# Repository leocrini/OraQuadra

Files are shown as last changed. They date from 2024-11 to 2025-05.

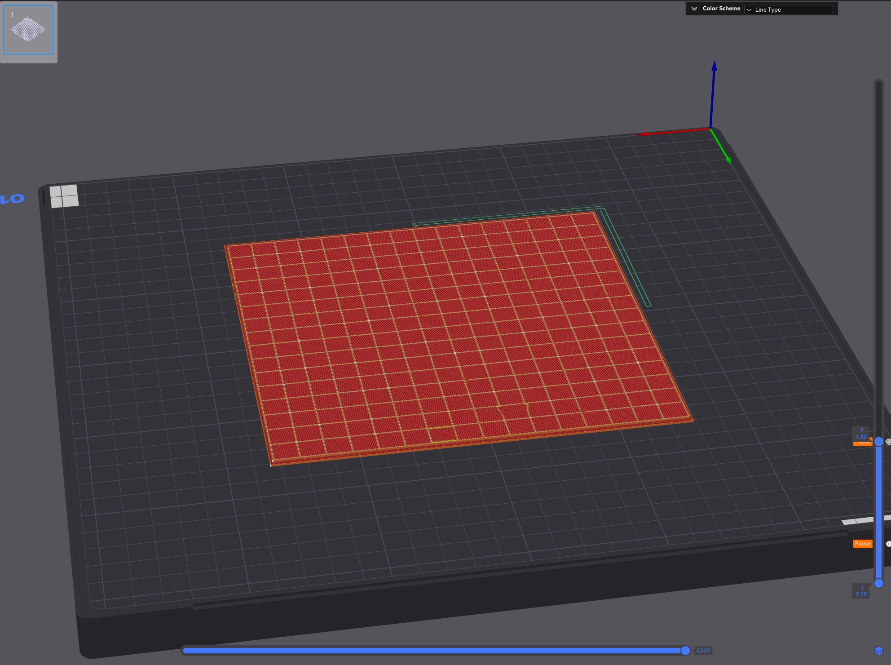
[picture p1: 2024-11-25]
3D/Frontale Monocolore/Pausa al layer 9.jpg

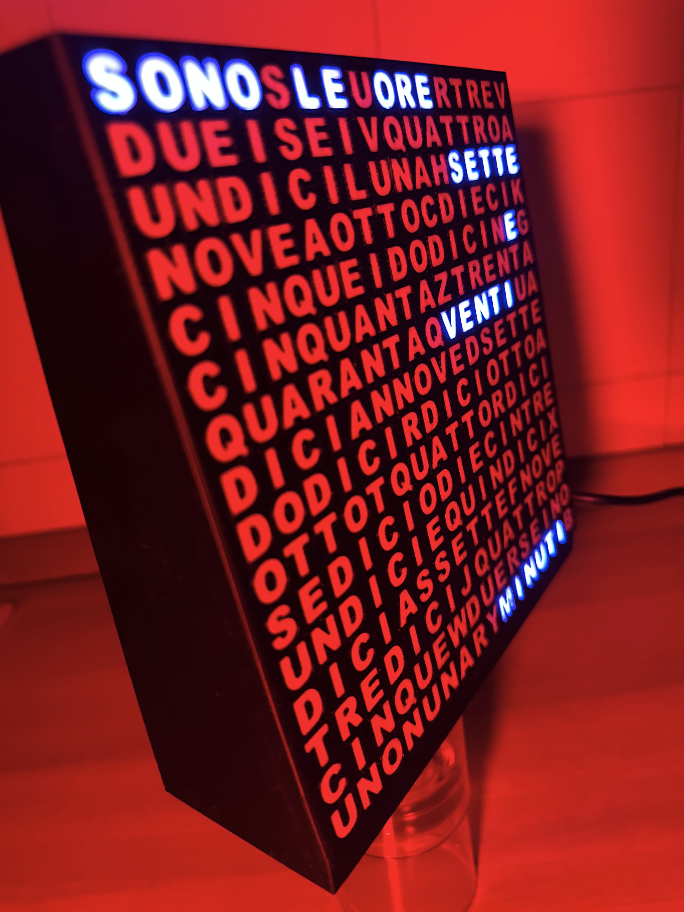
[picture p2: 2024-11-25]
IMMAGINI/IMG_9131.jpg

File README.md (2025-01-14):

# OraQuadra
Le parole in tempo

Un progetto per la comunità, per un simpatico orologio derivato dal progetto Word Clock, ma totalmente personalizzato e con tutto il necessario per poterselo replicare facilmente.
Video tutorial qui: https://youtu.be/s_7UZaXF4Ug





EPXX-OraQuadra



Nuova Versione che mostra l'ora nel formato 24 ore.

Versione_24_ore

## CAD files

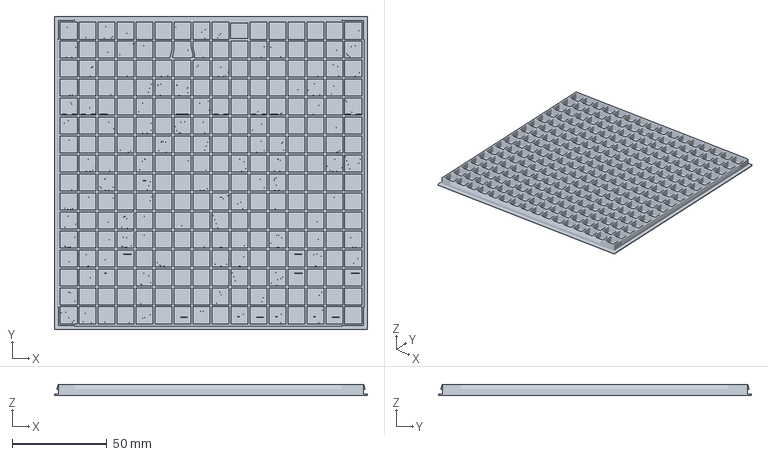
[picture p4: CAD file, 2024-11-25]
3D/BAMBULAB/Frontale_Bambulab.3mf
165.0 x 165.0 x 6.00 mm

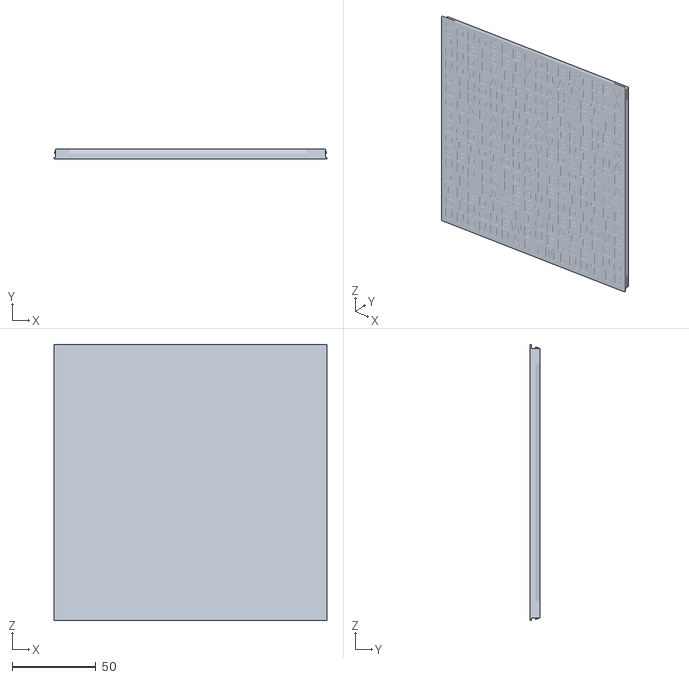
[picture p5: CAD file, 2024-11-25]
3D/Frontale Monocolore/Frontale Monocolore.stl
163.0 x 6.00 x 165.0

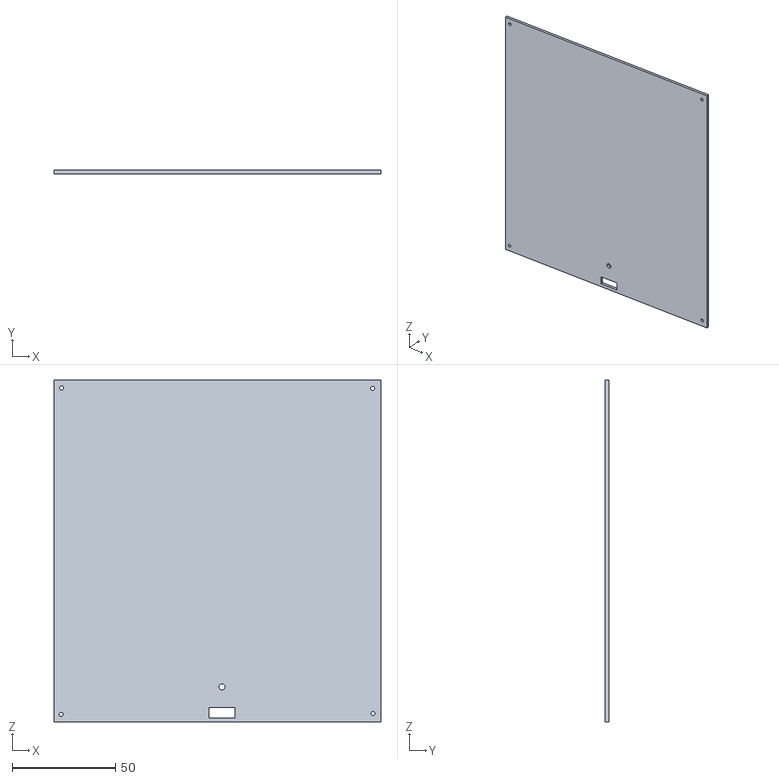
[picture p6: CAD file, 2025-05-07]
3D/Schiena da tavolo.stl
158.5 x 1.70 x 166.0

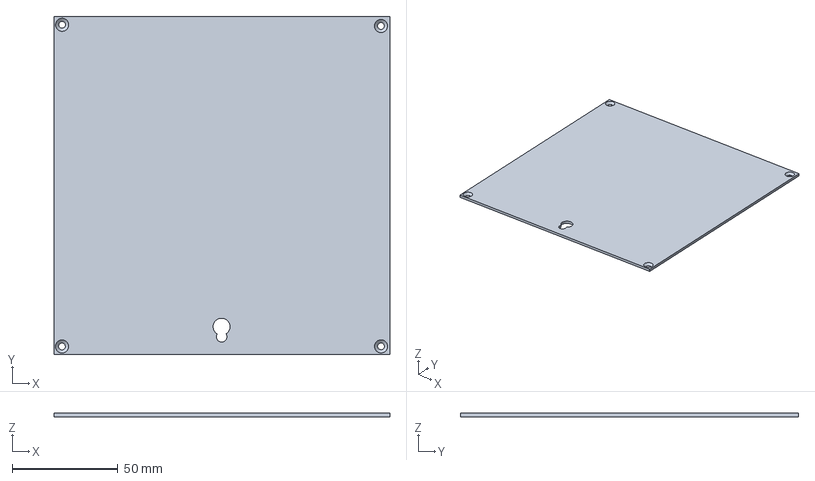
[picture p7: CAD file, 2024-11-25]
3D/BAMBULAB/Schiena da muro_bambulab.3mf
158.5 x 159.6 x 1.70 mm

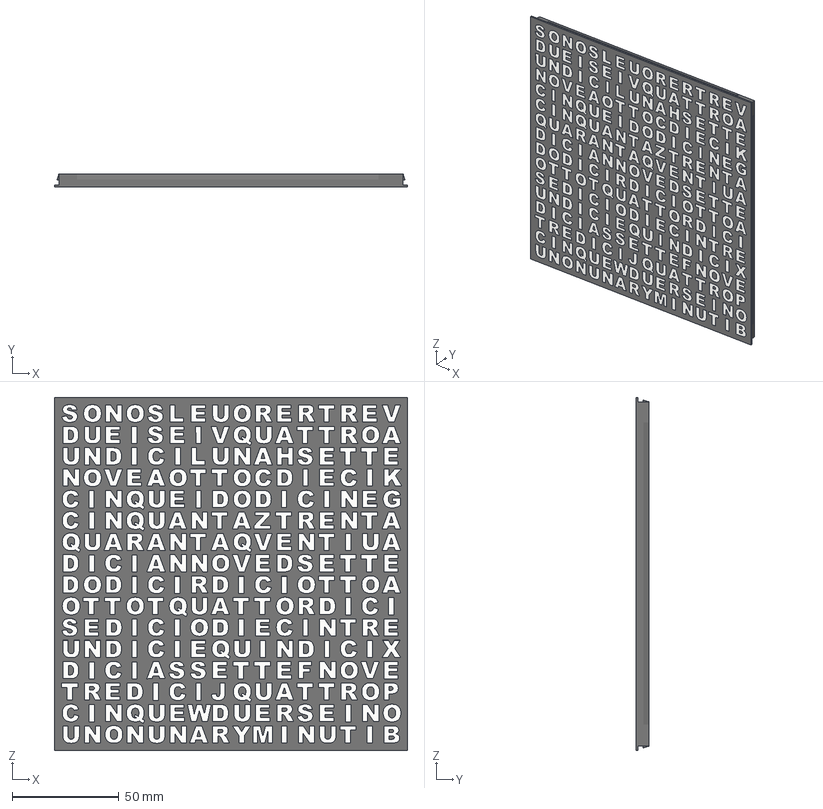
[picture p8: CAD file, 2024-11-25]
3D/Frontale Bicolore.3mf
165.0 x 6.00 x 165.0 mm
neoboard_led_diffuser_1mm_and_separator_4mm (1)
neoboard_led_diffuser_1mm_and_separator_4mm (10)
neoboard_led_diffuser_1mm_and_separator_4mm (11)
neoboard_led_diffuser_1mm_and_separator_4mm (12)
neoboard_led_diffuser_1mm_and_separator_4mm (13)
neoboard_led_diffuser_1mm_and_separator_4mm (14)
neoboard_led_diffuser_1mm_and_separator_4mm (15)
neoboard_led_diffuser_1mm_and_separator_4mm (16)
neoboard_led_diffuser_1mm_and_separator_4mm (17)
neoboard_led_diffuser_1mm_and_separator_4mm (18)
neoboard_led_diffuser_1mm_and_separator_4mm (19)
neoboard_led_diffuser_1mm_and_separator_4mm (2)
neoboard_led_diffuser_1mm_and_separator_4mm (20)
neoboard_led_diffuser_1mm_and_separator_4mm (21)
neoboard_led_diffuser_1mm_and_separator_4mm (22)
neoboard_led_diffuser_1mm_and_separator_4mm (23)
neoboard_led_diffuser_1mm_and_separator_4mm (24)
neoboard_led_diffuser_1mm_and_separator_4mm (25)
neoboard_led_diffuser_1mm_and_separator_4mm (26)
neoboard_led_diffuser_1mm_and_separator_4mm (27)
neoboard_led_diffuser_1mm_and_separator_4mm (28)
neoboard_led_diffuser_1mm_and_separator_4mm (29)
neoboard_led_diffuser_1mm_and_separator_4mm (3)
neoboard_led_diffuser_1mm_and_separator_4mm (30)
neoboard_led_diffuser_1mm_and_separator_4mm (31)
neoboard_led_diffuser_1mm_and_separator_4mm (32)
neoboard_led_diffuser_1mm_and_separator_4mm (33)
neoboard_led_diffuser_1mm_and_separator_4mm (34)
neoboard_led_diffuser_1mm_and_separator_4mm (35)
neoboard_led_diffuser_1mm_and_separator_4mm (36)
neoboard_led_diffuser_1mm_and_separator_4mm (37)
neoboard_led_diffuser_1mm_and_separator_4mm (38)
neoboard_led_diffuser_1mm_and_separator_4mm (39)
neoboard_led_diffuser_1mm_and_separator_4mm (4)
neoboard_led_diffuser_1mm_and_separator_4mm (40)
neoboard_led_diffuser_1mm_and_separator_4mm (41)
neoboard_led_diffuser_1mm_and_separator_4mm (42)
neoboard_led_diffuser_1mm_and_separator_4mm (43)
neoboard_led_diffuser_1mm_and_separator_4mm (44)
neoboard_led_diffuser_1mm_and_separator_4mm (45)
neoboard_led_diffuser_1mm_and_separator_4mm (46)
neoboard_led_diffuser_1mm_and_separator_4mm (47)
neoboard_led_diffuser_1mm_and_separator_4mm (48)
neoboard_led_diffuser_1mm_and_separator_4mm (49)
neoboard_led_diffuser_1mm_and_separator_4mm (5)
neoboard_led_diffuser_1mm_and_separator_4mm (50)
neoboard_led_diffuser_1mm_and_separator_4mm (51)
neoboard_led_diffuser_1mm_and_separator_4mm (52)
neoboard_led_diffuser_1mm_and_separator_4mm (53)
neoboard_led_diffuser_1mm_and_separator_4mm (54)
neoboard_led_diffuser_1mm_and_separator_4mm (55)
neoboard_led_diffuser_1mm_and_separator_4mm (56)
neoboard_led_diffuser_1mm_and_separator_4mm (57)
neoboard_led_diffuser_1mm_and_separator_4mm (58)
neoboard_led_diffuser_1mm_and_separator_4mm (59)
neoboard_led_diffuser_1mm_and_separator_4mm (6)
neoboard_led_diffuser_1mm_and_separator_4mm (60)
neoboard_led_diffuser_1mm_and_separator_4mm (61)
neoboard_led_diffuser_1mm_and_separator_4mm (62)
neoboard_led_diffuser_1mm_and_separator_4mm (63)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

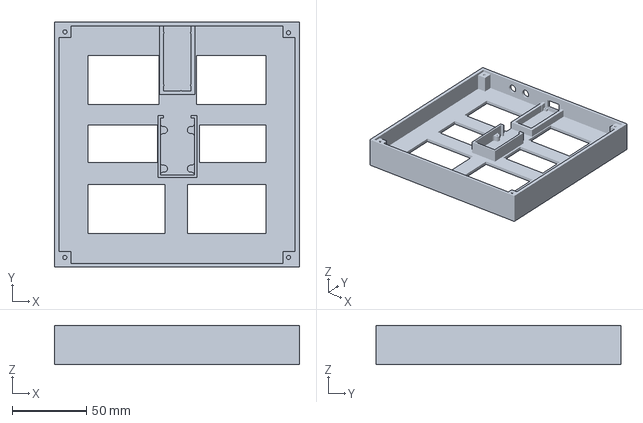
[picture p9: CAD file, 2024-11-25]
3D/BAMBULAB/Corpo da muro_bambulab.3mf
165.0 x 164.9 x 26.5 mm

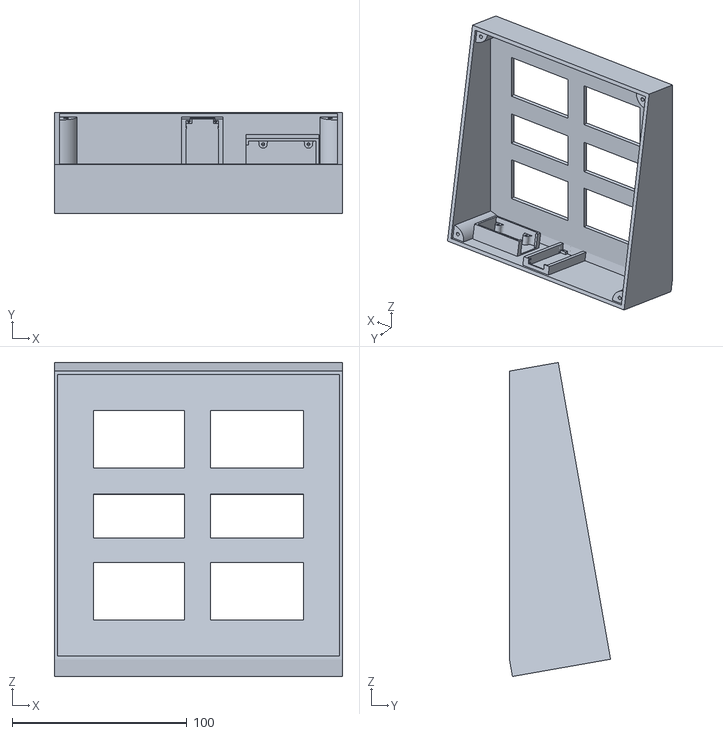
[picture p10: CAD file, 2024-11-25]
3D/Corpo da tavolo.stl
165.0 x 57.9 x 179.8

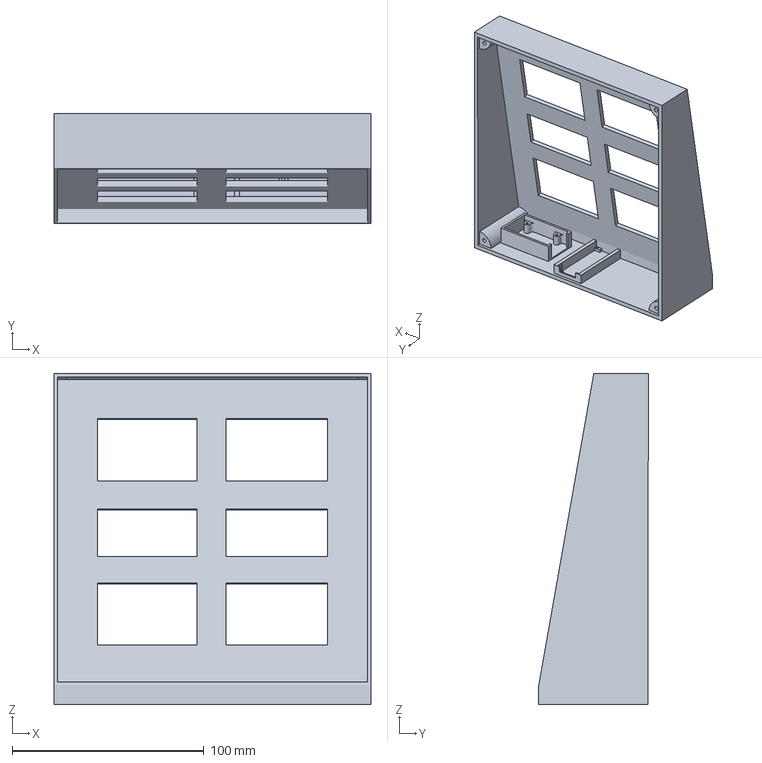
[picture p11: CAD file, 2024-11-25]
3D/BAMBULAB/Corpo da tavolo_bambulab.3mf
165.0 x 57.1 x 172.5 mm

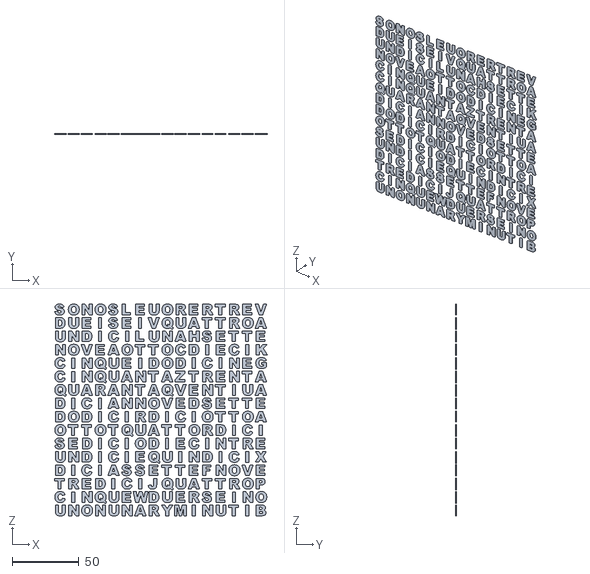
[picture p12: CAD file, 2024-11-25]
3D/Frontale bicolore lettere.stl
159.1 x 1.00 x 158.3

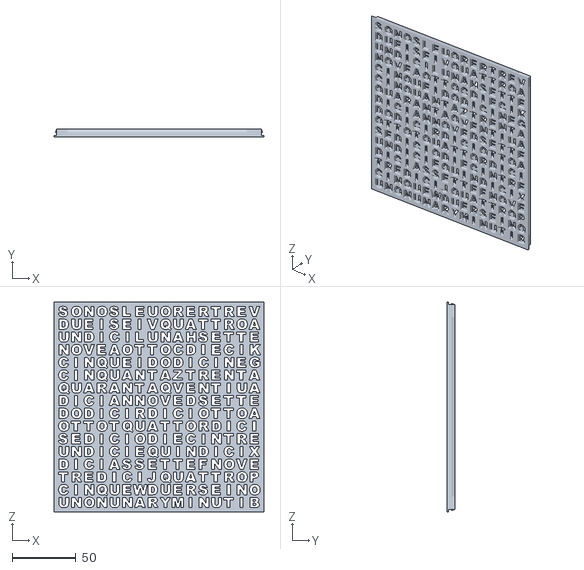
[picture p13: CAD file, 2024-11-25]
3D/Frontale bicolore corpo.stl
165.0 x 6.00 x 165.0

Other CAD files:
3D/BAMBULAB/Schiena da tavolo_bambulab.3mf
3D/Schiena da muro.stl
3D/Corpo da muro.stl

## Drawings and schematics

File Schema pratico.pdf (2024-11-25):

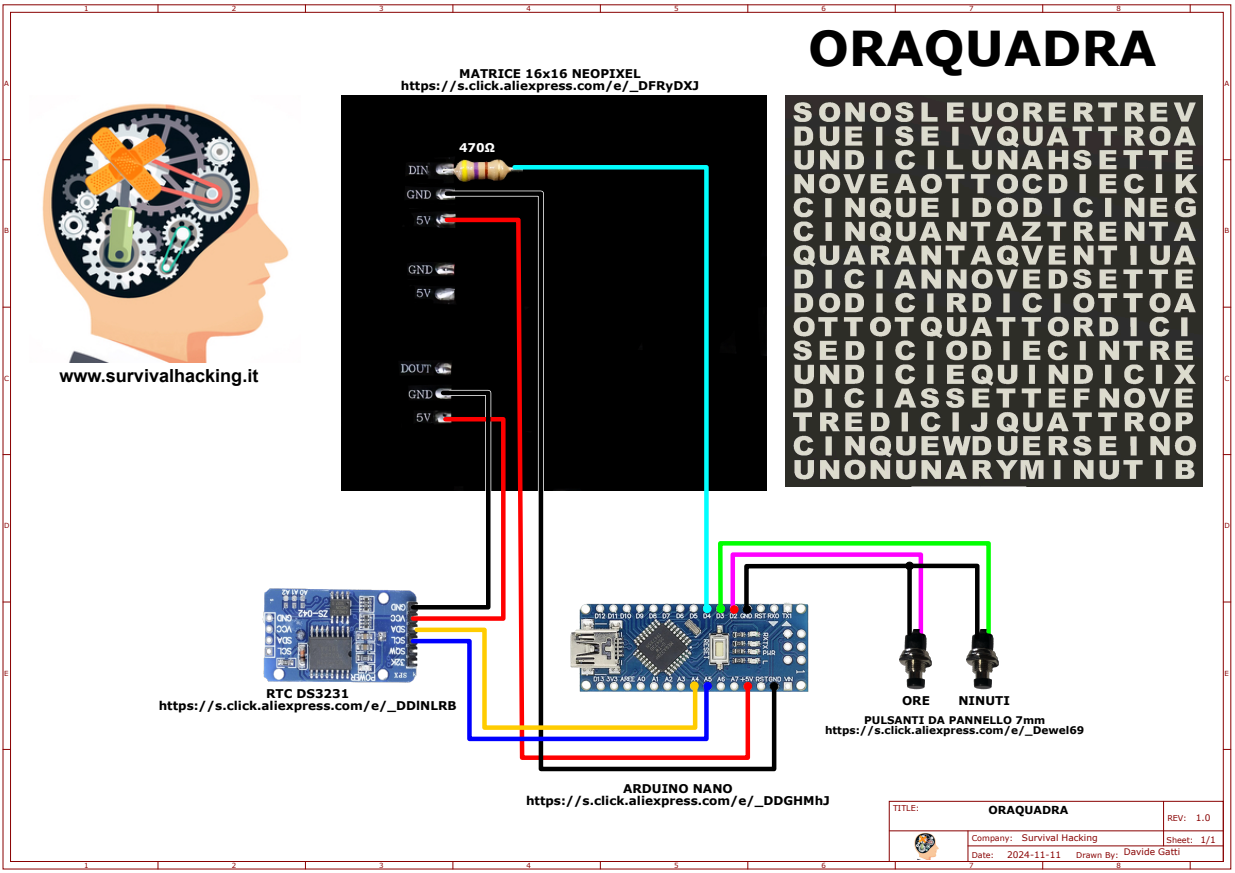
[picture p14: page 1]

https://s.click.aliexpress.com/e/_DFRyDXJ

https://s.click.aliexpress.com/e/_DDlNLRB

https://s.click.aliexpress.com/e/_Dewel69

https://s.click.aliexpress.com/e/_DDGHMhJ

TITLE: ORAQUADRA | REV: 1.0

Company: Survival Hacking | Sheet: 1/1

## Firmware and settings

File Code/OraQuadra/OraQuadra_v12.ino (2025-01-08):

// OraQuadra V1.2
// By Davide Gatti SURVIVAL HACKING  www.survivalhacking.it
//
// Setup:
//
// Pulsante 1 = per la regolazione dell'ora
// Pulsante 2 = per la regolazione deli minuti
// Pulsante 1 + Pulsante 2 = cambio preset 0=Sfumato bianco  1-5=Scrittura lenta vari colori  6-10=Scrittira veloce vari colori 11=Matrix classico 12=Multicolor fill
//
// Cambiati valori di luminosità di default per evitare che si bruci Arduino per l'eccessivo assorbimento della matrice LED 
//
// Modificato da Angelo Carrieri il 08/01/2025 con l'aggiunta di altri due modalità
// Modo 11=Effetto matrix classico
// Modo 12=Effetto multicolor fill

#include "RTClib.h"
#include <Adafruit_NeoPixel.h>
#include <EEPROM.h>

RTC_DS3231 rtc;       // Istanza per usare l'RTC

//Definizioni per neopixel
#define PIN   4        // pin neopixel
#define NUMPIXELS 256  // 16 x 16
#define GIORNO 64     // Luminosità di giorno (Attenzione, non alzare troppo questo valore visto che la matrice è alimentata dall'arduino che potrebbe bruciarsi se esagerate)
#define NOTTE 32       // Luminosità di notte

Adafruit_NeoPixel strip(NUMPIXELS, PIN, NEO_GRB + NEO_KHZ800);
byte intBrightness;

//Definizione colori
uint32_t Red = strip.Color(255, 0, 0); 
uint32_t Green = strip.Color( 0, 255, 0);
uint32_t Blue = strip.Color( 0, 0, 255);
uint32_t White = strip.Color( 255, 255, 255);
uint32_t Yellow = strip.Color( 255, 255, 0);
uint32_t Purple = strip.Color( 60, 0, 255);
uint32_t Gray = strip.Color( 128, 128, 128);
uint32_t Off = strip.Color( 0, 0, 0);

byte P1= 3; // Tasto O  avanzamento ore
byte P2= 2; // Tasto M  avanzamento minuti

byte oracorrente;        // variabile ora corrente
byte oraprecedente;      // variabile ora precedente
byte minutocorrente;     // variabile minuto corrente
byte minutoprecedente;   // variabile minuto precedente
byte mode;               // variabile per la modalità   
byte modo;               // variabile per la modalità mirror
byte Presets;            // Preset corrente
uint32_t Colore;         // Variabile per il passaggio colore
byte ledstrip[NUMPIXELS];   // Array di 256 byte per mappare i led da accendere per effetto Matrix

// Mappatura matrice
// S-015 O-014 N-013 O-012 S-011 L-010 E-009 U-008 O-007 R-006 E-005 R-004 T-003 R-002 E-001 V-000
// D-016 U-017 E-018 I-019 S-020 E-021 I-022 V-023 Q-024 U-025 A-026 T-027 T-028 R-029 O-030 A-031
// U-047 N-046 D-045 I-044 C-043 I-042 L-041 U-040 N-039 A-038 H-037 S-036 E-035 T-034 T-033 E-032
// N-048 O-049 V-050 E-051 A-052 O-053 T-054 T-055 O-056 C-057 D-058 I-059 E-060 C-061 I-062 K-063
// C-079 I-078 N-077 Q-076 U-075 E-074 I-073 D-072 O-071 D-070 I-069 C-068 I-067 N-066 E-065 G-064
// C-080 I-081 N-082 Q-083 U-084 A-085 N-086 T-087 A-088 Z-089 T-090 R-091 E-092 N-093 T-094 A-095
// Q-111 U-110 A-109 R-108 A-107 N-106 T-105 A-104 Q-103 V-102 E-101 N-100 T-099 I-098 U-097 A-096
// D-112 I-113 C-114 I-115 A-116 N-117 N-118 O-119 V-120 E-121 D-122 S-123 E-124 T-125 T-126 E-127
// D-143 O-142 D-141 I-140 C-139 I-138 R-137 D-136 I-135 C-134 I-133 O-132 T-131 T-130 O-129 A-128
// O-144 T-145 T-146 O-147 T-148 Q-149 U-150 A-151 T-152 T-153 O-154 R-155 D-156 I-157 C-158 I-159
// S-175 E-174 D-173 I-172 C-171 I-170 O-169 D-168 I-167 E-166 C-165 I-164 N-163 T-162 R-161 E-160
// U-176 N-177 D-178 I-179 C-180 I-181 E-182 Q-183 U-184 I-185 N-186 D-187 I-188 C-189 I-190 X-191
// D-207 I-206 C-205 I-204 A-203 S-202 S-201 E-200 T-199 T-198 E-197 F-196 N-195 O-194 V-193 E-192
// T-208 R-209 E-210 D-211 I-212 C-213 I-214 J-215 Q-216 U-217 A-218 T-219 T-220 R-221 O-222 P-223
// C-239 I-238 N-237 Q-236 U-235 E-234 W-233 D-232 U-231 E-230 R-229 S-228 E-227 I-226 N-225 O-224
// U-240 N-241 O-242 N-243 U-244 N-245 A-246 R-247 Y-248 M-249 I-250 N-251 U-252 T-253 I-254 B-255


//Definizione testi vari
byte  txtSONOLEORE[] = {15,14,13,12,10,9,7,6,5,255};
byte  txtSURVIVAL[] = {11,8,4,0,19,23,31,41,37,52,57,63,73,66,64,255};
byte  txtMINUTI[] = {249,250,251,252,253,254,255};

//Definizione delle stringhe delle ore
byte  txtUNA[] = {38,39,40,255};
byte  txtDUE[] = {16,17,18,255};
byte  txtTRE[] = {1,2,3,255};
byte  txtQUATTRO[] = {24,25,26,27,28,29,30,255};
byte  txtCINQUE[] = {79,78,77,76,75,74,255};
byte  txtSEI[] = {20,21,22,255};
byte  txtSETTE[] = {32,33,34,35,36,255};
byte  txtOTTO[] = {53,54,55,56,255};
byte  txtNOVE[] = {48,49,50,51,255};
byte  txtDIECI[] = {58,59,60,61,62,255};
byte  txtUNDICI[] = {42,43,44,45,46,47,255};
byte  txtDODOCI[] = {67,68,69,70,71,72,255};

// Definizione delle stringhe dei minuti
byte  txtE[] = {65,255};
byte  txtMUNO[] = {240,241,242,255};
byte  txtMDUE[] = {230,231,232,255};
byte  txtMTRE[] = {160,161,162,255};
byte  txtMQUATTRO[] = {216,217,218,219,220,221,222,255};
byte  txtMCINQUE[] = {234,235,236,237,238,239,255};
byte  txtMSEI[] = {226,227,228,255};
byte  txtMSETTE[] = {123,124,125,126,127,255};
byte  txtMOTTO[] = {144,145,146,147,255};
byte  txtMNOVE[] = {192,193,194,195,255};
byte  txtMDIECI[] = {164,165,166,167,168,255};
byte  txtMUNDICI[] = {176,177,178,179,180,181,255};
byte  txtMDODICI[] = {138,139,140,141,142,143,255};
byte  txtMTREDICI[] = {208,209,210,211,212,213,214,255};
byte  txtMQUATTORDICI[] = {149,150,151,152,153,154,155,156,157,158,159,255};
byte  txtMQUINDICI[] = {183,184,185,186,187,188,189,190,255};
byte  txtMSEDICI[] = {170,171,172,173,174,175,255};
byte  txtMDICIASSETTE[] = {197,198,199,200,201,202,203,204,205,206,207,255};
byte  txtMDICIOTTO[] = {129,130,131,132,133,134,135,136,255};
byte  txtMDICIANNOVE[] = {112,113,114,115,116,117,118,119,120,121,255};
byte  txtMVENT[] = {99,100,101,102,255};
byte  txtMVENTI[] = {98,99,100,101,102,255};
byte  txtMTRENT[] = {90,91,92,93,94,255};
byte  txtMTRENTA[] = {90,91,92,93,94,95,255};
byte  txtMQUARANT[] = {105,106,107,108,109,110,111,255};
byte  txtMQUARANTA[] = {104,105,106,107,108,109,110,111,255};
byte  txtMCINQUANT[] = {80,81,82,83,84,85,86,87,255};
byte  txtMCINQUANTA[] = {80,81,82,83,84,85,86,87,88,255};


void setup () {
  if (EEPROM.read(0) != 0x55) {           // read configuration byte. If it is not 55h is not configured, than store a default values
    EEPROM.write(0, 0x55);                // write configuret marker
    EEPROM.write(1, 0);                   // scrivi il Preset di default
  }
  
  Presets=(EEPROM.read(1));               // Leggi eeprom e imposta il preset memorizzato
  Preset(Presets);                        // imposta il modo grafico del relativo preset

  strip.begin();                          // inizializza matrice neo pixel
  strip.clear();                          // spegni tutti i led della matrice  
  rainbow(1);                             // faiun effetto arcobaleno
  for (int i =0 ; i < 500; i++) {        // Scrivi SURVIVAL HACKING in multicolor e poi flash bianchi 
    paintWordFast(random(254),strip.Color( random(254), random(254), random(254)));
    strip.show();
  }
  
  for (int i =0 ; i < 5; i++) {           // Scrivi SURVIVAL HACKING in multicolor e poi flash bianchi 
    paintWordFast(txtSURVIVAL, Red);
    paintWordFast(txtSURVIVAL, Blue);
    paintWordFast(txtSURVIVAL, Yellow);
    paintWordFast(txtSURVIVAL, Green);
    paintWordFast(txtSURVIVAL, White);
  }
//  delay(1000);
  for (int i =0 ; i < 100; i++) {        // Scrivi SURVIVAL HACKING in multicolor e poi flash bianchi 
    paintWordFast(random(255),strip.Color(0,0,0));
    paintWordFast(random(255),strip.Color(0,0,0));
    paintWordFast(random(255),strip.Color(0,0,0));
    paintWordFast(random(255),strip.Color(0,0,0));
    paintWordFast(random(255),strip.Color(0,0,0));
    paintWordFast(random(255),strip.Color(0,0,0));
    paintWordFast(random(255),strip.Color(0,0,0));
    paintWordFast(random(255),strip.Color(0,0,0));
    paintWordFast(random(255),strip.Color(0,0,0));
    paintWordFast(random(255),strip.Color(0,0,0));
//    paintWordFast(txtSURVIVAL, Off);
//    delay(1);
//    paintWordFast(txtSURVIVAL, White);
    strip.show();
  }
  strip.clear();
  strip.show();
  strip.setPixelColor(11,White);
  strip.show();                           // aggiorna matrice neopixel
  delay(200);
  strip.setPixelColor(8,White);
  strip.show();                           // aggiorna matrice neopixel
  delay(200);
  strip.setPixelColor(4,White);
  strip.show();                           // aggiorna matrice neopixel
  delay(200);
  strip.setPixelColor(0,White);
  strip.show();                           // aggiorna matrice neopixel
  delay(200);
  strip.setPixelColor(19,White);
  strip.show();                           // aggiorna matrice neopixel
  delay(200);
  strip.setPixelColor(23,White);
  strip.show();                           // aggiorna matrice neopixel
  delay(200);
  strip.setPixelColor(31,White);
  strip.show();                           // aggiorna matrice neopixel
  delay(200);
  strip.setPixelColor(41,White);
  strip.show();                           // aggiorna matrice neopixel
  delay(200);
  strip.setPixelColor(37,White);
  strip.show();                           // aggiorna matrice neopixel
  delay(200);
  strip.setPixelColor(52,White);
  strip.show();                           // aggiorna matrice neopixel
  delay(200);
  strip.setPixelColor(57,White);
  strip.show();                           // aggiorna matrice neopixel
  delay(200);
  strip.setPixelColor(63,White);
  strip.show();                           // aggiorna matrice neopixel
  delay(200);
  strip.setPixelColor(73,White);
  strip.show();                           // aggiorna matrice neopixel
  delay(200);
  strip.setPixelColor(66,White);
  strip.show();                           // aggiorna matrice neopixel
  delay(200);
  strip.setPixelColor(64,White);
  strip.show();                           // aggiorna matrice neopixel
  delay(1000);
  paintWordFast(txtSURVIVAL, Red);
  strip.show();                           // aggiorna matrice neopixel
  delay(1000);

  strip.clear();                          // spegni tutti i led della matrice  
  strip.show();                           // aggiorna matrice neopixel

  pinMode(P1,INPUT_PULLUP);               // definisce il tipo di ingresso digitale con pullup
  pinMode(P2,INPUT_PULLUP);               // definisce il tipo di ingresso digitale con pullup

  oraprecedente =99;                      // impostazione variabile per aggiornamento forzato ora
  minutoprecedente =99;                   // impostazione variabile per aggiornamento forzato ora

  if (! rtc.begin()) {                    // inizializza RTC  
    while (1) delay(10);                  // se non trova l'RTC si blocca qui all'infinito
  }

  if (rtc.lostPower()) {                  // se viene rilevata una perdita di alimentazione l'RTC si imposta con la data e ora programmata
    rtc.adjust(DateTime(F(__DATE__), F(__TIME__)));
  }
}

void loop () {
  if(!digitalRead(P1) && !digitalRead(P2)) {  // Se si schiacciano i due pulsanti in contemporanea si cambia il preset
    Presets+=1;
    if (Presets > 12) Presets=0;
    Preset(Presets);
    EEPROM.write(1, Presets);               // scrivi Preset in EEPROM
  } else if(!digitalRead(P1)) {             // se si preme il pulsante H si regolano le ore
    DateTime now = rtc.now();               // leggi ora dall'RTC
    int ora = now.hour();       
    int minuti = now.minute();
    ora+=1;                                 // incrementa ora 
    if (ora > 23 ) ora = 0;                 // controlla limiti 
    rtc.adjust(DateTime(2024,10,18,ora,minuti,0)); // scrivi ora nell'RTC
    delay(100); 
    mode=2;                                 // imposta modalità aggiornamento led veloce 
  } else if(!digitalRead(P2)) {             // se si preme il pulsante M si regolano i minuti 
    DateTime now = rtc.now();               // leggi ora dall'RTC
    int ora = now.hour();
    int minuti = now.minute();
    minuti+=1;                              // incrementa minuti
    if (minuti > 59 ) minuti = 0;           // controlla limiti 
    rtc.adjust(DateTime(2024,10,18,ora,minuti,0)); // scrivi ora nell'RTC
    delay(100);
    mode=2;                                 // imposta modalità aggiornamento led veloce 
  } else {
    mode=modo;                              // se non sono premuti tasti metti la modalità impostata dai Preset
  }
  DateTime now = rtc.now();               // leggi ora dall'RTC
  if((now.hour() < 7) || (now.hour() >= 19)){  // se nella fascia oraria dalle 19 alle 7 abbassa la luminosità
    intBrightness =  NOTTE;               // setta la luminosità notturna
  } else {
    intBrightness =  GIORNO;              // setta la luminosità giorno
  }
  strip.setBrightness(intBrightness);     // imposta la luminosità nella matrice neopixel
  strip.show();       	      			      // aggiorna la matrice

  minutocorrente = now.minute();          // imposta variabile locale dei minuti correnti
  oracorrente = now.hour();               // imposta variabile locale delle ore correnti

  paintWord(txtSONOLEORE, Colore, mode);   // scrivi 'SONO LE ORE'


  if (oracorrente != oraprecedente) {     // verifica se + cambiata l'ora
    AggiornaOre(oraprecedente,Off,2);     // cancella l'ora precedente
    AggiornaOre(oracorrente,Colore,mode); // scrivi l'ora corrente
    oraprecedente=oracorrente;            // imposta l'ora precedente
    strip.show();				                  // aggiorna la matrice
  }  

  if (minutocorrente != minutoprecedente) {       // verifica se + cambiati i minuti
    AggiornaMinuti(minutoprecedente,Off,2);       // cancella i minuti precedenti
    if (minutocorrente == 0) {                    // se minuti = 0 non scrivere "E"
      paintWord(txtE, Off,2);                     // cancella "E"
      paintWord(txtMINUTI, Off,2);                // cancella "MINUTI"
    } else {
      paintWord(txtE, Colore,mode);               // Se minuti <> 0 scrivi "E"
      AggiornaMinuti(minutocorrente,Colore,mode); // scrivi i minuti correnti
      paintWord(txtMINUTI, Colore,mode);          // Se minuti <> 0 scrivi "MINUTI"
    }
    minutoprecedente=minutocorrente;              // imposta l'ora precedente
    switch (modo) {
      case 0:
        strip.show();
        break;
      case 1:
        strip.show();
        break;
      case 2:
        strip.show();
        break;
      case 3:
        MatrixEffect();
        break;
      case 4:
        SnakeEffect();
        break;
    }

  }  
  strip.show();     				                      // aggiorna la matrice
  delay(500);                                     // attesa di un secondo per far pulsare la scritta se in modalità 0
}


void Preset(int Passedpreset) {                   // imposta preset grafico. 0=sufmato bianco 1-5=Scriturra lenta vari colori  6-10=Scrittura rapida vari colori  11=Effetto Matrix
  switch (Passedpreset) { 
  case 0:
    modo=0;
    Colore=White;
    break;    
  case 1:
    modo=1;
    Colore=White;
    break;    
  case 2:
    modo=1;
    Colore=Blue;
    break;    
  case 3:
    modo=1;
    Colore=Red;
    break;    
  case 4:
    modo=1;
    Colore=Purple;
    break;    
  case 5:
    modo=1;
    Colore=Green;
    break;    
  case 6:
    modo=2;
    Colore=White;
    break;    
  case 7:
    modo=2;
    Colore=Blue;
    break;    
  case 8:
    modo=2;
    Colore=Red;
    break;    
  case 9:
    modo=2;
    Colore=Purple;
    break;    
  case 10:
    modo=2;
    Colore=Green;
    break;    
  case 11:
    modo=3;
    Colore=White;
    clearStrip(); //Azzera i valori della striscia led
    break;    
  case 12:
    modo=4;
    Colore=Yellow;
    clearStrip(); //Azzera i valori della striscia led
    break;    
  }
  strip.clear();
  strip.show();
  oraprecedente =99;
  minutoprecedente =99;
  mode=modo;
  delay(500);
}


void AggiornaOre(byte ora,uint32_t Colore, byte modo) { // in base all'ora passata, scrive stringa dell'ora nella matrice
 switch (ora) { 
    case 99:
      break;
    case 0:
    case 12: 
    case 24:
      paintWord(txtDODOCI, Colore, modo);
      break;
    case 1:
    case 13:
      paintWord(txtUNA, Colore, modo);
      break;
    case 2:
    case 14:
      paintWord(txtDUE, Colore, modo);
      break;
    case 3:
    case 15:
      paintWord(txtTRE, Colore, modo);
      break;
    case 4:
    case 16:
      paintWord(txtQUATTRO, Colore, modo);
      break;
    case 5:
    case 17:
      paintWord(txtCINQUE, Colore, modo);
      break;
    case 6:
    case 18:
      paintWord(txtSEI, Colore, modo);
      break;
    case 7:
    case 19:
      paintWord(txtSETTE, Colore, modo);
      break;
    case 8:
    case 20:
      paintWord(txtOTTO, Colore, modo);
      break;
    case 9:
    case 21:
      paintWord(txtNOVE, Colore, modo);
      break;
    case 10:
    case 22:
      paintWord(txtDIECI, Colore, modo);
      break;
    case 11:
    case 23:
      paintWord(txtUNDICI, Colore, modo);
      break;
    }
}
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

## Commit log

2024-11-25 Stampe 3D
    [Corpo da muro.stl, Corpo da muro_bambulab.3mf, Corpo da tavolo.stl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]
2024-12-14 Arduino Code
2025-01-14 Versione 2 per nuovo pannello frontale 24 ore
    Questo sketch è per la versione del nuovo frontale che supporta le 24 ore grazie a Luca Bertalmio
2025-01-14 Nuovo frontale in grado di rappresentare l'ora nel formato 24 ore. Serve apposito sketch arduino
    Nuovo frontale in grado di rappresentare l'ora nel formato 24 ore. Serve apposito sketch arduino
    [Frontale Bicolore 24 ore.3mf]
2025-01-26 Schema pratico versione WLED by Gino in Ufficina
    Con una piccola modifica aggiungendo un ESP8266 e un deviatore, sarà possibile condividere il display a matrice con due diverse modalità di utilizzo.
    Il video completo su come programmare l'ESP con le funzionalità WLED, le potete trovare nel canale di Gino in Ufficina: https://www.youtube.com/@inufficinacongrisugino
2025-03-05 Oraquadra 2 files for ESP32
2025-03-05 Oraquadra 2 for arduino for retrofit old version
2025-03-05 File per nuova versione Oraquadra2 basato su ESP32
    [Corpo.stl, Frontale Bicolore 24 ore.3mf, Frontale-Bambulab 24 ore.3mf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]
2025-05-07 schiena con un solo foro per un solo pulsante
    [Schiena da tavolo.stl]
